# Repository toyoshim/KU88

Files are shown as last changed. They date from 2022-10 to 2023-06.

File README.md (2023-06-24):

# KU88
PCB and firmware to convert USB's MD mini controller to PC-8801 keyboard.

# Usage
START button changes the input mode as Normal Mode -> Tenkey Mode -> Normal Mode ...

## Normal Mode
Suitable keymap for RPG games such as The Legend of Heroes, and Hydlide.
Keyname written inside `()` is used while SELECT is pressed.
```
 7(7) 8(8) 9(9)
 4(4)  +   6(6)    F1(W) F2(R) F3(C)
 1(1) 2(2) 3(3)     RET   SPC  Z(ESC)
```
The numbers are 10-Key variants without the START being pressed, and normal one
with the START being pressed.
 
## Tenkey Mode
Suitable keymap for ADV games such as JESUS.
```
      S(V)       
 Y(Z)  +   N(C)     1(7)  2(8)  3(9)
     SPC(X)         0(4)  ,(5)  .(6)
```

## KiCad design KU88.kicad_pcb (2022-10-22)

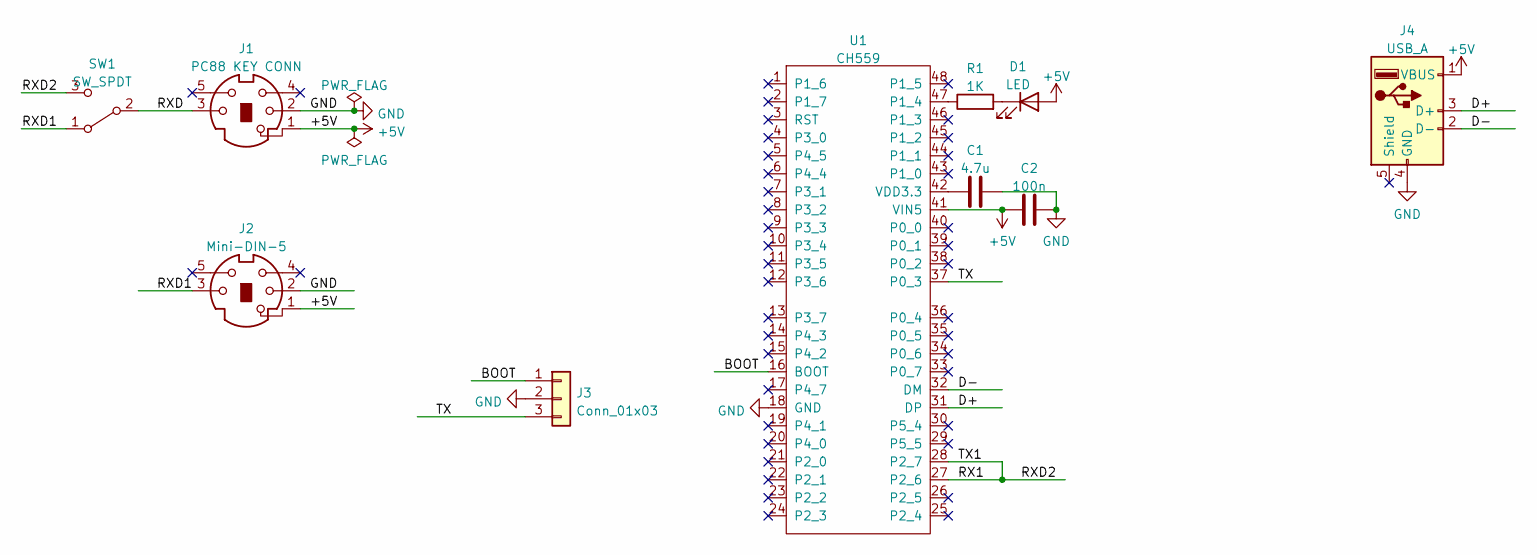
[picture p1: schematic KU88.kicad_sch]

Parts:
C1: 4.7u; C_0603_1608Metric_Pad1.08x0.95mm_HandSolder
C2: 100n; C_0603_1608Metric_Pad1.08x0.95mm_HandSolder
D1: LED; D_0603_1608Metric_Pad1.05x0.95mm_HandSolder
J1: PC88 KEY CONN; Mini-DIN 5 Pin Connector
J2: Mini-DIN-5; Mini-DIN 5 Pin Connector
J3: Conn_01x03; PinHeader_1x03_P2.54mm_Vertical
J4: USB_A; USB_A_Female_USB-AF-DIP-154-HW-S
R1: 1K; R_0603_1608Metric_Pad0.98x0.95mm_HandSolder
SW1: SW_SPDT; Switch_Slide_11.6x4mm_EG1218
U1: CH559; LQFP-48_7x7mm_P0.5mm

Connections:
+5V: C2.1, D1.2 (A), J1.1, J2.1, J4.1 (VBUS), U1.41 (VIN5)
/BOOT: J3.1, U1.16 (BOOT)
/D+: J4.3 (D+), U1.31 (DP)
/D-: J4.2 (D-), U1.32 (DM)
/RX1: SW1.3 (C), U1.27 (P2_6), U1.28 (P2_7)
/RXD: J1.3, SW1.2 (B)
/RXD1: J2.3, SW1.1 (A)
/TX: J3.3, U1.37 (P0_3)
GND: C1.2, C2.2, J1.2, J2.2, J3.2, J4.4 (GND), U1.18 (GND)
unnamed: C1.1, U1.42 (VDD3.3)
unnamed: D1.1 (K), R1.2
unnamed: R1.1, U1.47 (P1_4)

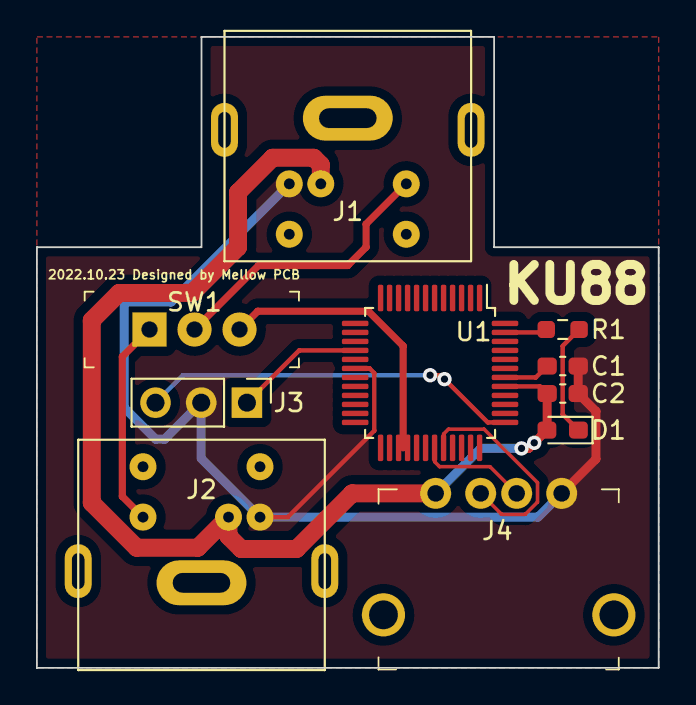
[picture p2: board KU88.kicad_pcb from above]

Board: 2 copper layers, 34.5 x 35.1 mm, 10 parts (0 on the bottom side), 12 nets.

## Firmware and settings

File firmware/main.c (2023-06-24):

// Copyright 2022 Takashi Toyoshima <toyoshim@gmail.com>.
// Use of this source code is governed by a BSD-style license that can be found
// in the LICENSE file.
#include <stdint.h>

#include "ch559.h"
#include "hid.h"
#include "key.h"
#include "led.h"
#include "serial.h"

enum {
  MODE_NORMAL = 0,
  MODE_TENKEY = 1,

  MODE_WRAP = 2,
};

uint8_t led_modes[] = {L_ON, L_BLINK};

uint8_t mode = 0;
bool start = false;

static bool button_check(uint16_t index, const uint8_t* data) {
  if (index == 0xffff)
    return false;
  uint8_t byte = index >> 3;
  uint8_t bit = index & 7;
  return data[byte] & (1 << bit);
}

static int8_t axis_check(const struct hub_info* info,
                         const uint8_t* data,
                         uint8_t index) {
  if (info->axis[index] == 0xffff)
    return 0;
  if (info->axis_size[index] == 8) {
    uint8_t v = data[info->axis[index] >> 3];
    if (info->axis_sign[index])
      v += 0x80;
    if (info->axis_polarity[index])
      v = 0xff - v;
    if (v < 0x60)
      return -1;
    if (v > 0xa0)
      return 1;
  } else if (info->axis_size[index] == 12) {
    uint8_t byte_index = info->axis[index] >> 3;
    uint16_t l = data[byte_index + 0];
    uint16_t h = data[byte_index + 1];
    uint16_t v = ((info->axis[index] & 7) == 0) ? (((h << 8) & 0x0f00) | l)
                                                : ((h << 4) | (l >> 4));
    if (info->axis_sign[index])
      v += 0x0800;
    if (info->axis_polarity[index])
      v = 0x0fff - v;
    if (v < 0x0600)
      return -1;
    if (v > 0x0a00)
      return 1;
  } else if (info->axis_size[index] == 16) {
    uint8_t byte = info->axis[index] >> 3;
    uint16_t v = data[byte] | ((uint16_t)data[byte + 1] << 8);
    if (info->axis_sign[index])
      v += 0x8000;
    if (info->axis_polarity[index])
      v = 0xffff - v;
    if (v < 0x6000)
      return -1;
    if (v > 0xa000)
      return 1;
  }
  return 0;
}

static void report(uint8_t hub,
                   const struct hub_info* info,
                   const uint8_t* data,
                   uint16_t size) {
  hub;
  size;

  if (info->type == HID_TYPE_KEYBOARD)
    return;
  if (info->report_id) {
    if (info->report_id != data[0])
      return;
    data++;
  }

  uint8_t u = button_check(info->dpad[0], data) ? 1 : 0;
  uint8_t d = button_check(info->dpad[1], data) ? 1 : 0;
  uint8_t l = button_check(info->dpad[2], data) ? 1 : 0;
  uint8_t r = button_check(info->dpad[3], data) ? 1 : 0;
  int8_t x = axis_check(info, data, 0);
  int8_t y = axis_check(info, data, 1);
  if (x < 0)
    l = 1;
  else if (x > 0)
    r = 1;
  if (y < 0)
    u = 1;
  else if (y > 0)
    d = 1;
  if (info->hat != 0xffff) {
    uint8_t byte = info->hat >> 3;
    uint8_t bit = info->hat & 7;
    uint8_t hat = (data[byte] >> bit) & 0xf;
    switch (hat) {
      case 0:
        u = 1;
        break;
      case 1:
        u = 1;
        r = 1;
        break;
      case 2:
        r = 1;
        break;
      case 3:
        r = 1;
        d = 1;
        break;
      case 4:
        d = 1;
        break;
      case 5:
        d = 1;
        l = 1;
        break;
      case 6:
        l = 1;
        break;
      case 7:
        l = 1;
        u = 1;
        break;
    }
  }

  bool current_start = button_check(info->button[HID_BUTTON_START], data);
  if (!start && current_start) {
    key_reset();
    mode = (mode + 1) % MODE_WRAP;
    led_mode(led_modes[mode]);
  }
  start = current_start;
  if (start) {
    return;
  }

  // MD mini pad
  //                SELECT
  //  +   START   4 1 L1
  //              3 2 R1
  bool alt = button_check(info->button[HID_BUTTON_SELECT], data);
  bool ba = button_check(info->button[HID_BUTTON_3], data);
  bool bb = button_check(info->button[HID_BUTTON_2], data);
  bool bc = button_check(info->button[HID_BUTTON_R1], data);
  bool bx = button_check(info->button[HID_BUTTON_4], data);
  bool by = button_check(info->button[HID_BUTTON_1], data);
  bool bz = button_check(info->button[HID_BUTTON_L1], data);
  if (mode == MODE_NORMAL) {
    // For The Legend of Heroes, and Hydlide.
    key_flip(0x0, 7, !alt && u && l);         // 7 (10-Key)
    key_flip(0x1, 0, !alt && u && !l && !r);  // 8 (10-Key)
    key_flip(0x1, 1, !alt && u && r);         // 9 (10-Key)
    key_flip(0x0, 1, !alt && d && l);         // 1 (10-Key)
    key_flip(0x0, 2, !alt && d && !l && !r);  // 2 (10-Key)
    key_flip(0x0, 3, !alt && d && r);         // 3 (10-Key)
    key_flip(0x0, 4, !alt && l && !u && !d);  // 4 (10-Key)
    key_flip(0x0, 6, !alt && r && !u && !d);  // 6 (10-Key)
    key_flip(0x6, 7, alt && u && l);          // 7
    key_flip(0x7, 0, alt && u && !l && !r);   // 8
    key_flip(0x7, 1, alt && u && r);          // 9
    key_flip(0x6, 1, alt && d && l);          // 1
    key_flip(0x6, 2, alt && d && !l && !r);   // 2
    key_flip(0x6, 3, alt && d && r);          // 3
    key_flip(0x6, 4, alt && l && !u && !d);   // 4
    key_flip(0x6, 6, alt && r && !u && !d);   // 6
    key_flip(0x1, 7, !alt && ba);             // RET
    key_flip(0x9, 6, !alt && bb);             // SPACE
    key_flip(0x5, 2, !alt && bc);             // Z
    key_flip(0x9, 1, !alt && bx);             // F1
    key_flip(0x9, 2, !alt && by);             // F2
    key_flip(0x9, 3, !alt && bz);             // F3
    key_flip(0x4, 7, alt && bx);              // W
    key_flip(0x4, 2, alt && by);              // R
    key_flip(0x2, 3, alt && bz);              // C
    key_flip(0x9, 7, alt && bc);              // ESC
  } else if (mode == MODE_TENKEY) {
    // For JESUS.
    key_flip(0x0, 0, !alt && ba);  // 0
    key_flip(0x1, 5, !alt && bb);  // ,
    key_flip(0x1, 6, !alt && bc);  // .
    key_flip(0x0, 1, !alt && bx);  // 1
    key_flip(0x0, 2, !alt && by);  // 2
    key_flip(0x0, 3, !alt && bz);  // 3
    key_flip(0x0, 4, alt && ba);   // 4
    key_flip(0x0, 5, alt && bb);   // 5
    key_flip(0x0, 6, alt && bc);   // 6
    key_flip(0x0, 7, alt && bx);   // 7
    key_flip(0x1, 0, alt && by);   // 8
    key_flip(0x1, 1, alt && bz);   // 9
    key_flip(0x4, 3, !alt && u);   // S
    key_flip(0x9, 6, !alt && d);   // SPACE
    key_flip(0x5, 1, !alt && l);   // Y
    key_flip(0x3, 6, !alt && r);   // N
    key_flip(0x5, 2, alt && u);    // Z
    key_flip(0x5, 0, alt && d);    // X
    key_flip(0x2, 3, alt && l);    // C
    key_flip(0x4, 6, alt && r);    // V
  }
}

static void detected() {
  led_oneshot(L_PULSE_ONCE);
}

static uint8_t get_flags() {
  return USE_HUB0;
}

void main() {
  initialize();

  led_init(1, 4, LOW);
  led_mode(led_modes[mode]);

  key_init();

  struct hid hid;
  hid.report = report;
  hid.detected = detected;
  hid.get_flags = get_flags;
  hid_init(&hid);

  for (;;) {
    led_poll();
    hid_poll();
    key_flush();
  }
}

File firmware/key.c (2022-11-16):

// Copyright 2022 Takashi Toyoshima <toyoshim@gmail.com>.
// Use of this source code is governed by a BSD-style license that can be found
// in the LICENSE file.
#include "key.h"

#include "ch559.h"
#include "io.h"
#include "uart1.h"

static bool dirty_rows[0x0f] = {false, false, false, false, false,
                                false, false, false, false, false,
                                false, false, false, false, false};

static uint8_t rows[0x0f] = {
    0xff, 0xff, 0xff, 0xff, 0xff, 0xff, 0xff, 0xff,
    0xff, 0xff, 0xff, 0xff, 0xff, 0xff, 0x7f,
};

static volatile uint8_t int_count = 0;
static volatile uint16_t int_data = 0;

void key_int_tmr0() __interrupt INT_NO_TMR0 __using 0 {
  if (0 == int_count)
    return;
  if (int_count < 15) {
    // 1: Start-bit
    // 2-5: R0-3
    // 6-13: D0-D7
    // 14: Parity
    P2_7 = int_data & 1;
    int_data >>= 1;
  } else {
    P2_7 = 1;
  }
  // reset to 0 after 50t blank period.
  int_count = (int_count + 1) & 0x3f;
}

static void update_row(uint8_t row, uint8_t data) {
  uint16_t bits = (row & 0x0f) | (data << 4);
  uint8_t popc = 0;
  for (uint16_t bit = 1; bit != (1 << 12); bit <<= 1) {
    if (bits & bit)
      popc++;
  }
  if (popc & 1)
    bits |= (1 << 12);
  while (int_count)
    ;
  int_data = bits << 1;
  int_count = 1;
}

void key_init() {
  uart1_init(UART1_P4, UART1_115200);  // Release P2_7.
  pinMode(2, 7, OUTPUT);
  digitalWrite(2, 7, HIGH);

  TMOD = (TMOD | bT0_M1) & ~bT0_M0;  // Timer0 mode 2
  TL0 = 0;
  TH0 = 64;  // Fsys (48MHz) / 12 / (256 - TH) = 20800 (1T = 48usec)
  ET0 = 1;   // Timer0 interrupt enable.
  EA = 1;    // Global interrupt enable.
  TR0 = 1;   // Start timer count.
}

void key_reset() {
  for (int i = 0; i < 14; ++i)
    rows[i] = 0xff;
  rows[14] = 0x7f;
}

void key_flip(uint8_t row, uint8_t data, bool set) {
  uint8_t mask = 1 << data;
  bool was_set = 0 == (rows[row] & mask);
  if (was_set != set) {
    dirty_rows[row] = true;
    if (set) {
      rows[row] &= ~mask;
    } else {
      rows[row] |= mask;
    }
  }

  // TODO: emmit legacy combination for new keys.
}

void key_flush() {
  for (uint8_t i = 0; i < 0x0f; ++i) {
    if (!dirty_rows[i])
      continue;
    dirty_rows[i] = false;
    update_row(i, rows[i]);
  }
}
